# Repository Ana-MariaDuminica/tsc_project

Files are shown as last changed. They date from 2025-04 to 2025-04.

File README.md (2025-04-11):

# TSC-Project

## BOM (Bill Of Materials)

| Component | Supplier Link | Datasheet |
|---|---|---|
| 112A-TAAR-R03 | [Model](https://store.comet.srl.ro/Catalogue/Product/43497/) | [Datasheet](https://www.snapeda.com/parts/112A-TAAR-R03/Attend/datashee)|
| 744043680 | [Model](https://ro.mouser.com/ProductDetail/Wurth-Elektronik/744043680?qs=PGXP4M47uW6VkZq%252BkzjrHA%3D%3D) | [Datasheet](https://www.we-online.com/components/products/datasheet/744043680.pdf) |
| BD5229G-TR | [Model](https://componentsearchengine.com/part-view/BD5229G-TR/ROHM%20Semiconductor) | [Datasheet](https://fscdn.rohm.com/en/products/databook/datasheet/ic/power/voltage_detector/bd52xxg-e.pdf) |
| Capacitor 0402  | [Model](https://ro.mouser.com/c/passive-components/capacitors/ceramic-capacitors/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) | [Datasheet](https://componentsearchengine.com/Datasheets/2/CC0402MRX5R5BB106.pdf) |
| CPH3225A | [Model](https://www.snapeda.com/parts/CPH3225A/Seiko+Instruments/view-part/?ref=snap) | [Datasheet](https://www.snapeda.com/parts/CPH3225A/Seiko%20Instruments/datasheet/) |
| Custom Button | [Model](https://industry.panasonic.com/global/en/products/control/switch/light-touch/number/evqpuj02k) | [Datasheet](https://industry.panasonic.com/global/en/downloads?tab=catalog&small_g_cd=203&part_no=EVQPUJ02K) |
| DS3231SN | [Model](https://www.snapeda.com/parts/DS3231SN%23/Analog+Devices/view-part/?ref=eda) | [Datasheet](https://www.snapeda.com/parts/DS3231SN%23/Analog%20Devices/datasheet/) |
| ESP32 WROVER 0805 Capacitor | [Model](https://github.com/anaobreja/TSC-Project/blob/main) | [Datasheet](https://github.com/anaobreja/TSC-Project/blob/main) |
| ESP32 WROVER BME680 Sensor | [Model](https://www.snapeda.com/parts/BME680/Bosch/view-part/?welcome=home) | [Datasheet](https://www.bosch-sensortec.com/media/boschsensortec/downloads/datasheets/bst-bme680-ds001.pdf) |
| ESP32 WROVER MCP73831 Power Management | [Model](https://www.snapeda.com/parts/BME680/Bosch/view-part/?welcome=home) | [Datasheet](https://www.snapeda.com/parts/MCP73831T-2ACI/OT/Microchip/datasheet/) |
| ESP32C6 Varistor 1812 | [Model](https://github.com/anaobreja/TSC-Project/blob/main) | [Datasheet](https://github.com/anaobreja/TSC-Project/blob/main) |
| ESP32C6 WROOM-1-N8 | [Model](https://www.snapeda.com/parts/ESP32-C6-WROOM-1-N8/Espressif+Systems/view-part/?ref=eda) | [Datasheet](https://www.snapeda.com/parts/ESP32-C6-WROOM-1-N8/Espressif%20Systems/datasheet/) |
| FH34SRJ-24S-0.5SH | [Model](https://ro.mouser.com/ProductDetail/Hirose-Connector/FH34SRJ-24S-0.5SH99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) | [Datasheet](https://www.snapeda.com/parts/FH34SRJ-24S-0.5SH(99)/Hirose%20Connector/datasheet/) |
| LED Chip 0603 | [Model](https://www.snapeda.com/parts/KP-1608SURCK/Kingbright/view-part/?ref=search&t=LED%200603) | [Datasheet](https://www.snapeda.com/parts/KP-1608SURCK/Kingbright/datasheet/) |
| MAX17048G+T10 | [Model](https://www.snapeda.com/parts/MAX17048G+T10/Analog+Devices/view-part/?ref=eda) | [Datasheet](https://www.snapeda.com/parts/MAX17048G+T10/Analog%20Devices/datasheet/) |
| MBR0530 Schottky Diode | [Model](https://www.snapeda.com/parts/MBR0530/Onsemi/view-part/?ref=snap) | [Datasheet](https://www.snapeda.com/parts/MBR0530/ON%20Semiconductor/datasheet/) |
| PGB1010603MR | [Model](https://www.snapeda.com/parts/PGB1010603MR/Littelfuse/view-part/?ref=eda) | [Datasheet](https://www.snapeda.com/parts/PGB1010603MR/Littelfuse%20Inc./datasheet/) |
| QWIIC Connector | [Model](https://www.snapeda.com/parts/PRT-14417/SparkFun/view-part/) | [Datasheet](https://www.snapeda.com/parts/PRT-14417/SparkFun%20Electronics/datasheet/) |
| RCL CPOL 3528 | [Model](https://www.snapeda.com/parts/CPH3225A/Seiko+Instruments/view-part/?ref=eda) | [Datasheet](https://s3.amazonaws.com/snapeda/datasheet/TAJB475K025RNJ_AVX.pdf) |
| Resistor 0402 | [Model](https://grabcad.com/library/resistor-0402-1) | [Datasheet](https://www.yageo.com/upload/media/product/products/datasheet/rchip/PYu-RC_Group_51_RoHS_L_12.pdf) |
| SI1308EDL-T1-GE3 MOSFET | [Model](https://www.snapeda.com/parts/SI1308EDL-T1-GE3/Vishay+Siliconix/view-part/?welcome=home&ref=eda) | [Datasheet](https://www.snapeda.com/parts/SI1308EDL-T1-GE3/Vishay%20Siliconix/datasheet/) |
| SJ | [Model](https://grabcad.com/library/solder-jumpers-1) | [Datasheet](https://github.com/anaobreja/TSC-Project/blob/main) |
| USB4110-GF-A | [Model](https://componentsearchengine.com/part-view/USB4110-GF-A/GCT%20(GLOBAL%20CONNECTOR%20TECHNOLOGY)) | [Datasheet](https://gct.co/files/drawings/usb4110.pdf) |
| USBLC6-2SC6Y | [Model](https://www.snapeda.com/parts/USBLC6-2SC6Y/STMicroelectronics/view-part/?welcome=home&ref=eda) | [Datasheet](https://www.winbond.com/resource-files/W25Q512JV%20SPI%20RevB%2006252019%20KMS.pdf) |
| W25Q512JVEIQ | [Model](https://www.snapeda.com/parts/W25Q512JVEIQ/Winbond+Electronics/view-part/?ref=eda) | [Datasheet](https://www.winbond.com/resource-files/W25Q512JV%20SPI%20RevB%2006252019%20KMS.pdf) |
| XC6220A331MR-G | [Model](https://componentsearchengine.com/part-view/XC6220A331MR-G/Torex) | [Datasheet](https://product.torexsemi.com/system/files/series/xc6220.pdf) |

## Hardware Description

**Microcontroller – ESP32-C6-WROOM-1-N8**  
The ESP32-C6 serves as the central processing unit, responsible for handling all system-level operations, communication with peripherals, and power management.  
**Architecture:** RISC-V 32-bit, **Clock Speed:** 160 MHz, **Wireless Connectivity:** 2.4 GHz Wi-Fi 6, Bluetooth 5.0  

**Power Management & Battery**  
Battery Type: Li-Po (Lithium Polymer), Capacity: 3.7V 1800mAh, Charging Circuit: MCP73831T, Input Voltage: 5V via USB-C, Protection Features: Overcharge and deep discharge protection, Voltage Regulator: LDO regulator providing 3.3V stable output  

**Display – E-Paper (E-Ink)**  
Screen Size: 7.5 inches, Resolution: 800x480 pixels, Communication Interface: SPI  

**SD Card Module**  
Type: MicroSD (supports FAT32), Interface: SPI  

**External NOR Flash**  
Capacity: 64MB, Interface: SPI  

**Environmental Sensor – BME688**  
Functions: Measures temperature, humidity, pressure, and gas levels, Communication Interface: I2C  

**Real-Time Clock (RTC) – DS3231SN**  
Functionality: Maintains time and date during power-off, Communication Interface: I2C  

**USB-C Connector & ESD Protection**  
Functionality: Provides power and data transfer, Protection: ESD protection and Schottky diode for reverse polarity  

**Buttons & User Input**  
Tactile push buttons for user interaction  

**Communication Interfaces**  
GPIO: Button control and general I/O, SPI: SD Card, NOR Flash, E-Paper Display, I2C: BME688 and DS3231SN, UART: Serial communication and debugging, Wi-Fi & Bluetooth: via ESP32-C6  

## Power Consumption Estimation
| Component | Current Draw (mA) | Voltage (V) | Power (mW) | Typical Current Range (mA) | Notes |
|---|---|---|---|---|---|
| ESP32-C6 (Wi-Fi active) | 140 | 3.3 | 462 | 120 – 160 | High usage during communication |
| E-Paper Display (Updating) | 20 | 3.3 | 66 | 15 – 26 | Active only during refresh |
| BME688 Sensor (Measuring) | 2.1 | 3.3 | 6.93 | 1.7 – 3.1 | Low-power environmental sensing |
| RTC Module (Active) | 0.8 | 3.3 | 2.64 | 0.5 – 1 | Minimal power requirement |
| SD Card (Active) | 60 | 3.3 | 198 | 30 – 100 | Used during data access |
| External NOR Flash (e.g. W25Q32) | 10 | 3.3 | 33 | 4 – 20 | Accessed for storage operations |

## ESP32-C6 Pin Mapping

| Component | Interface | Purpose | ESP32-C6 Pin(s) |
|---|---|---|---|
| E-Paper Display | SPI | Transfers image data to the display and controls its state | IO7 (MOSI), IO6 (SCK), IO10 (CS), IO5 (DC), IO23 (RST), IO3 (BUSY) |
| MicroSD Card | SPI | Allows storage and retrieval of e-book files | IO7 (MOSI), IO6 (SCK), IO4 (SS_SD), IO2 (MISO) |
| Environmental Sensor (BME688) | I2C | Reads temperature, humidity, pressure, and air quality data | IO21 (SDA), IO22 (SCL) |
| USB-C Connection | USB | Powers and programs the ESP32-C6 | GPIOs through voltage regulation |
| Control Buttons | GPIO | User input for device interactions | IO9 (BOOT), IO15 (CHANGE), EN (RESET) |
| RTC Module (DS3231) | I2C | Keeps track of time even when ESP32 is off | IO21 (SDA), IO22 (SCL), IO18 (RST), IO1 (32KHz), IO0 (INT_RTC) |
| External NOR Flash | SPI | Provides additional storage for application data | IO11 (CS), IO6 (SCK), IO2 (MISO), IO7 (MOSI) |
| Battery Monitoring | I2C | Reads battery voltage and charge status | IO21 (SDA), IO22 (SCL) |

## Design Notes

- The final PCB layout includes approximately **120 vias**, used primarily to optimize routing between layers while keeping signal integrity and clearance constraints in check.

- The following footprint and pad adjustments were manually made for compatibility with routing rules (specifically Copper Width DRC):

  **1. Inductor – L1 (IND_4828-WE-TPC_WRE)**  
  Footprint pad size was increased to **32mil × 16mil** to accommodate 0.3 mm (11.8mil) power traces without triggering DRC width violations.

  **2. Fuel Gauge – U4 (MAX17048G+T10, footprint SON50P200X200X80-9N)**  
  The original pad size of **29.92mil × 10.63mil** was modified to **32mil × 16mil** to ensure proper trace connection without violating clearance or minimum width rules.

- These changes ensure that all traces, especially for power delivery, comply with the netclass requirements (e.g., minimum 0.3 mm width for VBAT, VBUS, etc.) and eliminate false-positive DRC errors.

## Block Diagram

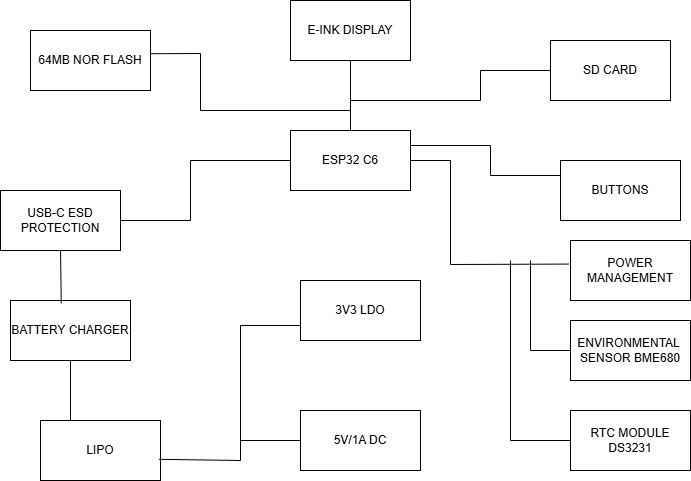
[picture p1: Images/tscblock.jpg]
Block Diagram


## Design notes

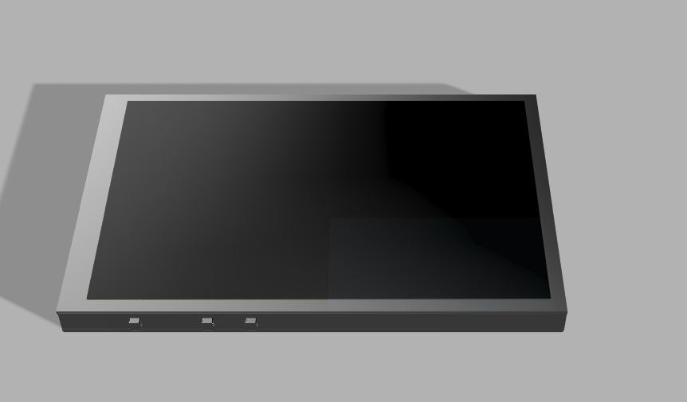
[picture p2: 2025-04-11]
Images/3d_model_image.png

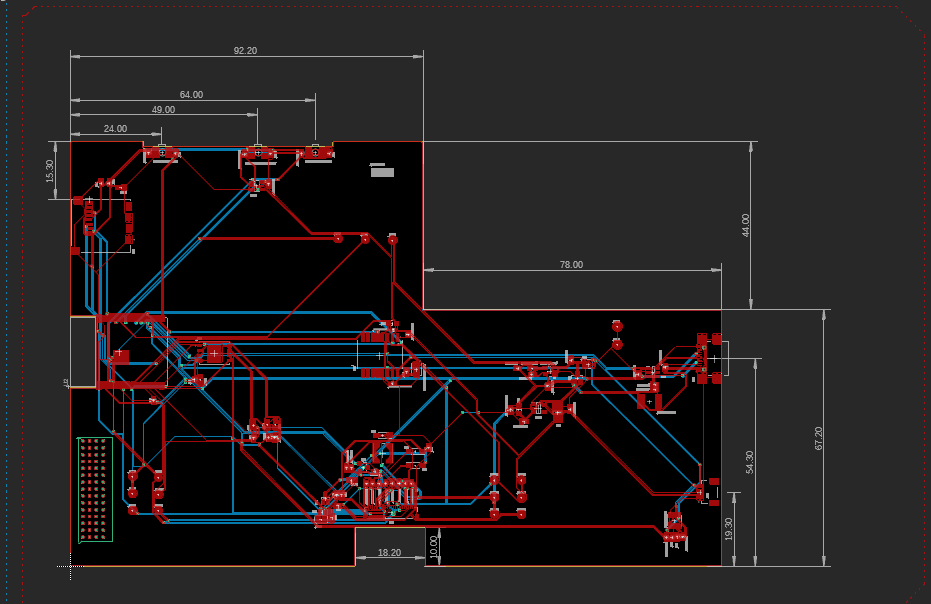
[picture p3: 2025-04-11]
Images/pcb2.png

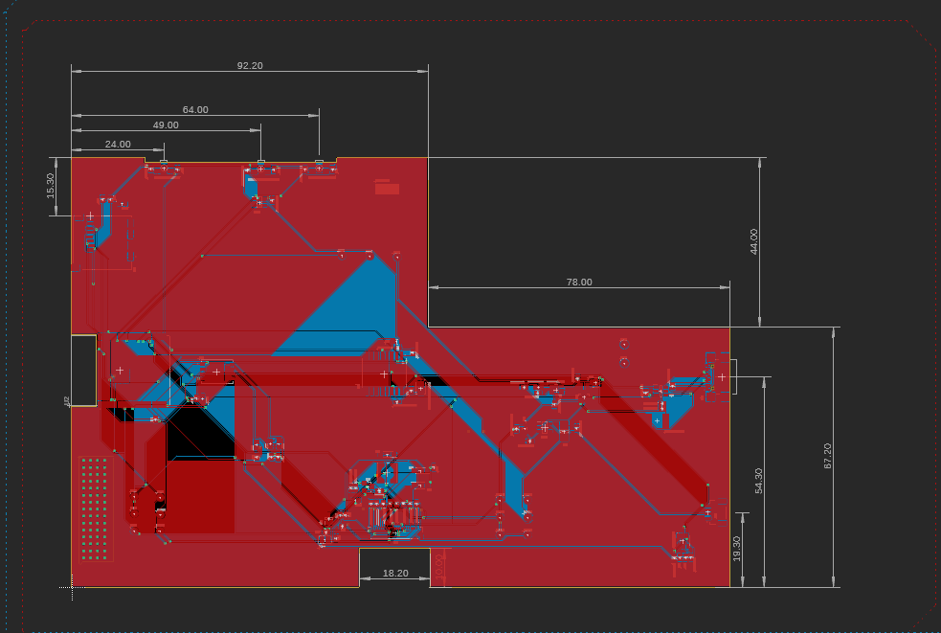
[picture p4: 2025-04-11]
Images/pcb1.png

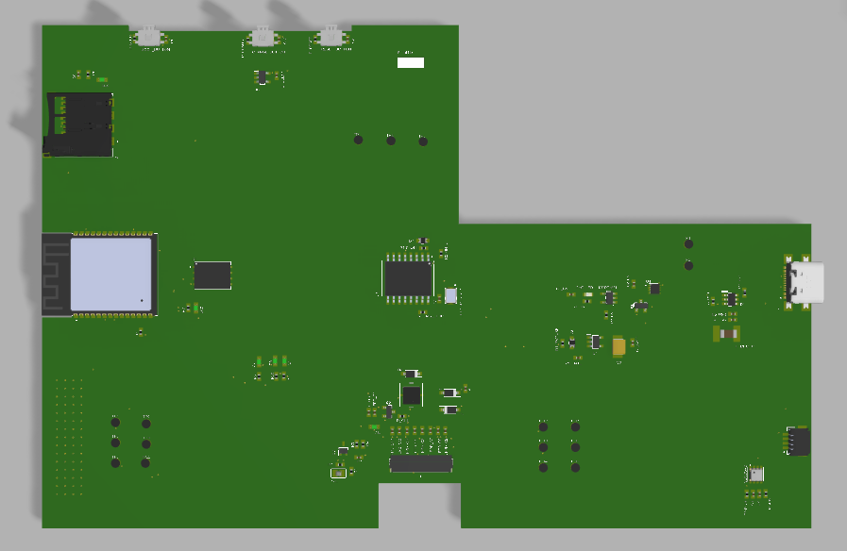
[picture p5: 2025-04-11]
Images/3d_board.png

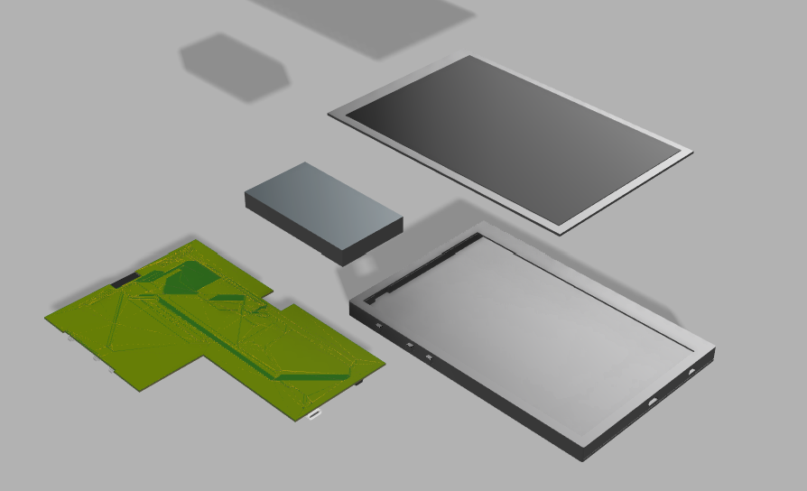
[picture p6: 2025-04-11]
Images/exploded_image.png

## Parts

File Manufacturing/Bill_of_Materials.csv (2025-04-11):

Qty | Value | Device | Package | Parts | Description | ARROW_PART_NUMBER | ARROW_PRICE-STOCK | AVAILABILITY | CENTROID_NOT_SPECIFIED | CHECK_PRICES | COPYRIGHT | DATASHEET | DESCRIPTION | DIGIKEY_DESCRIPTION | DIGIKEY_PART_NUMBER | HEIGHT | LEAD_FREE | MANUFACTURER_NAME | MANUFACTURER_PART_NUMBER | MF | MFR_NAME | MOUSER_PART_NUMBER | MOUSER_PRICE-STOCK | MOUSER_TESTING_PART_NUMBER | MOUSER_TESTING_PRICE-STOCK | MP | MPN | PACKAGE | POPULARITY | PREFIX | PRICE | PROD_ID | PURCHASE-URL | ROHS | SNAPEDA_LINK | SPICEMODEL | SPICEPREFIX | TEMPERATURE_RANGE_HIGH | TEMPERATURE_RANGE_LOW | TP_SIGNAL_NAME | VALUE
1 |  | ADAFRUIT_LEDCHIP-LED0603 | ADAFRUIT_CHIP-LED0603 | CHG_LED | LED
1 |  | SJ | SJ | SJ1 | SMD solder JUMPER |  |  |  |  |  |  |  |  |  |  |  |  |  |  |  |  |  |  |  |  |  |  |  | 3
1 | 0.1uF/50V | ESP32_WROVER_EAGLE-LTSPICE_CC0402 | ESP32_WROVER_EAGLE-LTSPICE_C0402 | EPD_C5 | CAPACITOR, European symbol |  |  |  |  |  |  |  |  |  |  |  |  |  |  |  |  |  |  |  |  |  |  |  |  |  |  |  |  |  |  | NONE | C
1 | 0.47 | ESP32_WROVER_EAGLE-LTSPICE_RR0402 | ESP32_WROVER_EAGLE-LTSPICE_R0402 | R3 | RESISTOR, European symbol |  |  |  |  |  |  |  |  |  |  |  |  |  |  |  |  |  |  |  |  |  |  |  |  |  |  |  |  |  |  | NONE | R
1 | 100K | ESP32_WROVER_EAGLE-LTSPICE_RR0402 | ESP32_WROVER_EAGLE-LTSPICE_R0402 | R1_PWRUSB | RESISTOR, European symbol |  |  |  |  |  |  |  |  |  |  |  |  |  |  |  |  |  |  |  |  |  |  |  |  |  |  |  |  |  |  | NONE | R
3 | 100nF | EAGLE-LTSPICE_CC0402 | EAGLE-LTSPICE_C0402 | C4_USB, C8, C9 | CAPACITOR, European symbol |  |  |  |  |  |  |  |  |  |  |  |  |  |  |  |  |  |  |  |  |  |  |  |  |  |  |  |  |  |  | NONE | C
5 | 100nF | ESP32_WROVER_EAGLE-LTSPICE_CC0402 | ESP32_WROVER_EAGLE-LTSPICE_C0402 | C1, C2, C6, C10, C_DELAY | CAPACITOR, European symbol |  |  |  |  |  |  |  |  |  |  |  |  |  |  |  |  |  |  |  |  |  |  |  |  |  |  |  |  |  |  | NONE | C
1 | 100uF TANT | RCL_CPOL-EUCT3528 | RCL_CT3528 | C3 | POLARIZED CAPACITOR, European symbol |  |  |  |  |  |  |  |  |  |  |  |  |  |  |  |  |  |  |  |  |  |  |  | 0 |  |  |  |  |  |  |  | C
16 | 10K | ESP32_WROVER_EAGLE-LTSPICE_RR0402 | ESP32_WROVER_EAGLE-LTSPICE_R0402 | R1, R1-PINH, R1-PINH1, R2-PINH, R2-PINH1, R4, R5, R6, R7, R8, R9, R10, R_BOOT, R_CHANGE, R_CL1, R_RESET | RESISTOR, European symbol |  |  |  |  |  |  |  |  |  |  |  |  |  |  |  |  |  |  |  |  |  |  |  |  |  |  |  |  |  |  | NONE | R
1 | 10uF | EAGLE-LTSPICE_CC0402 | EAGLE-LTSPICE_C0402 | C7 | CAPACITOR, European symbol |  |  |  |  |  |  |  |  |  |  |  |  |  |  |  |  |  |  |  |  |  |  |  |  |  |  |  |  |  |  | NONE | C
1 | 112A-TAAR-R03_ATTEND | 112A-TAAR-R03_ATTEND | 112ATAARR03ATTEND | J4 | Micro SD Card Socket, Push-Push Type, Top Mount, SMT, H=1.83mm, 10u |  |  |  |  |  |  |  | Micro SD Card Socket | Push-Push Type | Top Mount | SMT | H=1.83mm | 10u |  |  | 1.9mm |  | ATTEND | 112A-TAAR-R03 ATTEND
1 | 15 | ESP32_WROVER_EAGLE-LTSPICE_RR0402 | ESP32_WROVER_EAGLE-LTSPICE_R0402 | R_CAPACITOR | RESISTOR, European symbol |  |  |  |  |  |  |  |  |  |  |  |  |  |  |  |  |  |  |  |  |  |  |  |  |  |  |  |  |  |  | NONE | R
1 | 1uF | ESP32_WROVER_EAGLE-LTSPICE_CC0402 | ESP32_WROVER_EAGLE-LTSPICE_C0402 | C5 | CAPACITOR, European symbol |  |  |  |  |  |  |  |  |  |  |  |  |  |  |  |  |  |  |  |  |  |  |  |  |  |  |  |  |  |  | NONE | C
9 | 1uF/50V | ESP32_WROVER_EAGLE-LTSPICE_CC0402 | ESP32_WROVER_EAGLE-LTSPICE_C0402 | EPD_C1, EPD_C2, EPD_C6, EPD_C7, EPD_C8, EPD_C9, EPD_C10, EPD_C11, EPD_C12 | CAPACITOR, European symbol |  |  |  |  |  |  |  |  |  |  |  |  |  |  |  |  |  |  |  |  |  |  |  |  |  |  |  |  |  |  | NONE | C
1 | 2.2 | ESP32_WROVER_EAGLE-LTSPICE_RR0402 | ESP32_WROVER_EAGLE-LTSPICE_R0402 | R2 | RESISTOR, European symbol |  |  |  |  |  |  |  |  |  |  |  |  |  |  |  |  |  |  |  |  |  |  |  |  |  |  |  |  |  |  | NONE | R
1 | 200 | ESP32_WROVER_EAGLE-LTSPICE_RR0402 | ESP32_WROVER_EAGLE-LTSPICE_R0402 | R1_BAT | RESISTOR, European symbol |  |  |  |  |  |  |  |  |  |  |  |  |  |  |  |  |  |  |  |  |  |  |  |  |  |  |  |  |  |  | NONE | R
2 | 20V/4.2A/52m?/1.4W | ESP32_WROVER_SPARKFUN-DISCRETESEMI_MOSFET_PCH-DMG2305UX-7 | ESP32_WROVER_SPARKFUN-DISCRETESEMI_SOT23-3 | Q1, Q2 | P-channel MOSFETs |  |  |  |  |  |  |  |  |  |  |  |  |  |  |  |  |  |  |  |  |  |  |  |  |  |  | TRAN-14388 |  |  |  |  |  |  |  |  | 20V/4.2A/52m?/1.4W
1 | 2K | ESP32_WROVER_EAGLE-LTSPICE_RR0402 | ESP32_WROVER_EAGLE-LTSPICE_R0402 | R2_BAT | RESISTOR, European symbol |  |  |  |  |  |  |  |  |  |  |  |  |  |  |  |  |  |  |  |  |  |  |  |  |  |  |  |  |  |  | NONE | R
3 | 4.7uF | EAGLE-LTSPICE_CC0402 | EAGLE-LTSPICE_C0402 | C1_BAT1, C1_BAT2, C5_USB | CAPACITOR, European symbol |  |  |  |  |  |  |  |  |  |  |  |  |  |  |  |  |  |  |  |  |  |  |  |  |  |  |  |  |  |  | NONE | C
2 | 4.7uF | ESP32_WROVER_EAGLE-LTSPICE_CC0402 | ESP32_WROVER_EAGLE-LTSPICE_C0402 | C1_BAT, C2_BAT | CAPACITOR, European symbol |  |  |  |  |  |  |  |  |  |  |  |  |  |  |  |  |  |  |  |  |  |  |  |  |  |  |  |  |  |  | NONE | C
1 | 4.7uF/25V | EAGLE-LTSPICE_CC0402 | EAGLE-LTSPICE_C0402 | C4 | CAPACITOR, European symbol |  |  |  |  |  |  |  |  |  |  |  |  |  |  |  |  |  |  |  |  |  |  |  |  |  |  |  |  |  |  | NONE | C
2 | 5k1 | ESP32_WROVER_EAGLE-LTSPICE_RR0402 | ESP32_WROVER_EAGLE-LTSPICE_R0402 | R2-USB, R2-USB1 | RESISTOR, European symbol |  |  |  |  |  |  |  |  |  |  |  |  |  |  |  |  |  |  |  |  |  |  |  |  |  |  |  |  |  |  | NONE | R
1 | 68uH | 744043680IND_4828-WE-TPC_WRE | IND_4828-WE-TPC_WRE | L1 |  |  |  |  |  |  | Copyright (C) 2024 Ultra Librarian. All rights reserved. |  |  |  |  |  |  |  | 744043680 |  | Wurth Electronics
1 | BD5229G-TR | BD5229G-TR | SOT95P280X125-5N | IC1 | Voltage Detector with Adjustable Delay Time: CMOS processes are utilized to develop high precision, low current consumption CMOS reset ICs that allow arbitrary setting of the delay time. The extensive lineup includes both Nch Open Drain and CMOS output types in a wide range of detection voltages (from 2.3V to 6.0V, in 0.1V steps), enabling selection of the ideal solution based on customer requirements. In addition, the entire series is of course both lead-free and RoHS-compliant. |  |  |  |  |  |  |  | Voltage Detector with Adjustable Delay Time: CMOS processes are utilized to develop high precision | low current consumption CMOS reset ICs that allow arbitrary setting of the delay time. The extensive lineup includes both Nch Open Drain and CMOS output types in a wide range of detection voltages (from 2.3V to 6.0V | in 0.1V steps) | enabling selection of the ideal solution based on customer requirements. In addition | the entire series is of course both lead-free and RoHS-compliant. |  |  | 1.25mm |  | ROHM Semiconductor | BD5229G-TR |  |  | 755-BD5229G-TR | https://www.mouser.co.uk/ProductDetail/ROHM-Semiconductor/BD5229G-TR?qs=4kLU8WoGk0vvnhrrYwdszw%3D%3D
1 | BME688 | ESP32_WROVER_BME680_BME680 | ESP32_WROVER_BME680_PSON80P300X300X100-8N | SENSOR2 | Integrated Environmental Unit |  |  | Unavailable |  |  |  |  | Integrated Environmental Unit |  |  |  |  |  |  | Bosch Sensortec |  |  |  |  |  | BME680 |  | LGA-8 Bosch Tools |  |  | None
3 | BUTTON_CUSYOMV1 | BUTTON_CUSYOMV1 | MYBUTTON | BOOT_BUTTON, CHANGE_BUTTON, RESET_BUTTON
1 | CPH3225A | CPH3225A | CAPCP3225X100N | C10_SUPERCAP | Cap 0.011F 3.3V 1210 Flat Check availability |  |  | Not in stock |  | https://www.snapeda.com/parts/CPH3225A/Seiko+Instruments/view-part/?ref=eda |  |  | 11 mF (EDLC) Supercapacitor 3.3 V 1210 (3225 Metric) - - |  |  |  |  |  |  | Seiko Instruments |  |  |  |  |  | CPH3225A |  | 1210 Seiko |  |  | None |  | https://www.snapeda.com/api/url_track_click_mouser/?unipart_id=562593&manufacturer=Seiko Instruments&part_name=CPH3225A&search_term=None |  | https://www.snapeda.com/parts/CPH3225A/Seiko+Instruments/view-part/?ref=snap
1 | DS3231SN# | DS3231SN# | SOIC127P1032X265-16N | U3 | Real Time Clock Serial 16-Pin SOIC W T/R Check availability |  |  | In Stock |  | https://www.snapeda.com/parts/DS3231SN%23/Analog+Devices/view-part/?ref=eda |  |  | Extremely Accurate I2C-Integrated RTC/TCXO/Crystal |  |  |  |  |  |  | Analog Devices |  |  |  |  |  | DS3231SN# |  | SOIC-16 Maxim |  |  | None |  | https://www.snapeda.com/api/url_track_click_mouser/?unipart_id=99048&manufacturer=Analog Devices&part_name=DS3231SN#&search_term=None |  | https://www.snapeda.com/parts/DS3231SN%23/Analog+Devices/view-part/?ref=snap
1 | ESP32-C6-WROOM-1-N8 | ESP32-C6-WROOM-1-N8 | XCVR_ESP32-C6-WROOM-1-N8 | U2 | Check availability |  |  | In Stock |  | https://www.snapeda.com/parts/ESP32-C6-WROOM-1-N8/Espressif+Systems/view-part/?ref=eda |  |  | Multiprotocol Modules ESP32-C6 module | Wi-Fi 6 in 2.4 GHz band | Bluetooth 5 | Zigbee 3.0 and Thread. ESP34-WROOM Compatible - ENGINEERING SAMPLE |  |  |  |  |  |  | Espressif Systems |  |  |  |  |  | ESP32-C6-WROOM-1-N8 |  | None |  |  | None |  |  |  | https://www.snapeda.com/parts/ESP32-C6-WROOM-1-N8/Espressif+Systems/view-part/?ref=snap
1 | ESP32C6_VARISTORCN1812 | ESP32C6_VARISTORCN1812 | ESP32C6_VARISTOR_CT/CN1812 | PFMF.050.1 | VARISTOR |  |  |  |  |  |  |  |  |  |  |  |  |  |  |  |  |  |  |  |  |  |  |  | 0
1 | ESP32_WROVER_SPARKFUN-IC-POWER_MCP73831 | ESP32_WROVER_SPARKFUN-IC-POWER_MCP73831 | ESP32_WROVER_SPARKFUN-IC-POWER_SOT23-5 | MCP73831 | MCP73831T Li-Ion, Li-Pol Controller |  |  |  |  |  |  |  |  |  |  |  |  |  |  |  |  |  |  |  |  |  |  |  |  |  |  | IC-09995
1 | FH34SRJ-24S-0.5SH_99_ | FH34SRJ-24S-0.5SH_99_ | FH34SRJ24S05SH99 | J1 | (0.50mm) Surface Mount, Right Angle |  |  |  |  |  |  |  | 24 Position FFC | FPC Connector Contacts | (0.50mm) Surface Mount | Right Angle |  |  | 1.1mm |  | Hirose | FH34SRJ-24S-0.5SH(99) |  |  | 798-FH34SRJ24S05SH99 | https://www.mouser.co.uk/ProductDetail/Hirose-Connector/FH34SRJ-24S-0.5SH99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
1 | MAX17048G+T10 | MAX17048G+T10 | SON50P200X200X80-9N | U4 | Check availability |  |  | In Stock |  | https://www.snapeda.com/parts/MAX17048G+T10/Analog+Devices/view-part/?ref=eda |  |  | 3µA 1-Cell/2-Cell Fuel Gauge with ModelGauge |  |  |  |  |  |  | Analog Devices |  |  |  |  |  | MAX17048G+T10 |  | TDFN-8 Maxim |  |  | None |  | https://www.snapeda.com/api/url_track_click_mouser/?unipart_id=329239&manufacturer=Analog Devices&part_name=MAX17048G+T10&search_term=None |  | https://www.snapeda.com/parts/MAX17048G+T10/Analog+Devices/view-part/?ref=snap
3 | MBR0530 | MBR0530 | SOD3716X135N | D3, D4, D5 | ON SEMICONDUCTOR - MBR0530 - DIODE, SCHOTTKY, 0.5A, 30V, SOD-123 |  |  | In Stock |  | https://www.snapeda.com/parts/MBR0530/Onsemi/view-part/?ref=eda |  |  | Diode Schottky 30 V 500mA Surface Mount SOD-123 |  |  |  |  |  |  | ON Semiconductor |  |  |  |  |  | MBR0530 |  | SOD-123-2 ON Semiconductor |  |  | None |  | https://www.snapeda.com/api/url_track_click_mouser/?unipart_id=179458&manufacturer=ON Semiconductor&part_name=MBR0530&search_term=None |  | https://www.snapeda.com/parts/MBR0530/Onsemi/view-part/?ref=snap
6 | PGB1010603MR | PGB1010603MR | DIOC1608X36N | D6, D8, D9, D10, D11, D12 | Check availability |  |  | In Stock |  | https://www.snapeda.com/parts/PGB1010603MR/Littelfuse/view-part/?ref=eda |  |  | 150V (Typ) Clamp - Ipp Tvs Diode Surface Mount 0603 (1608 Metric) |  |  |  |  |  |  | Littelfuse Inc. |  |  |  |  |  | PGB1010603MR |  | 0603 Littelfuse Inc. |  |  | None |  | https://www.snapeda.com/api/url_track_click_mouser/?unipart_id=5659453&manufacturer=Littelfuse Inc.&part_name=PGB1010603MR&search_term=None |  | https://www.snapeda.com/parts/PGB1010603MR/Littelfuse/view-part/?ref=snap
1 | QWIIC_RIGHT_ANGLE | QWIIC_CONNECTORJS-1MM | JST04_1MM_RA | J3 | SparkFun I2C Standard Qwiic Connector |  |  |  |  |  |  |  |  |  |  |  |  |  |  |  |  |  |  |  |  |  |  |  |  |  |  | CONN-13694 |  |  |  |  |  |  |  |  | QWIIC_RIGHT_ANGLE
1 | SAMACSYS_PARTS_USB4110-GF-A | SAMACSYS_PARTS_USB4110-GF-A | SAMACSYS_PARTS_USB4110GFA | J2 | CONN USB 2.0 TYPE-C R/A SMT |  |  |  |  |  |  |  | CONN USB 2.0 TYPE-C R/A SMT |  |  | 3.26mm |  | GCT (GLOBAL CONNECTOR TECHNOLOGY) | USB4110-GF-A |  |  | 640-USB4110-GF-A | https://www.mouser.co.uk/ProductDetail/GCT/USB4110-GF-A?qs=KUoIvG%2F9IlYiZvIXQjyJeA%3D%3D
2 | SD0805S020S1R0 | ESP32_WROVER_AVX---SD0805S020S1R0_AVX_SD0805S020S1R0_0_0AVX_SD0805S020S1R0_0_0 | ESP32_WROVER_AVX---SD0805S020S1R0_AVX_SD0805S020S1R0_0 | D2, D7 | Schottky Barrier Rectifier Diode |  |  |  | No |  |  | http://datasheets.avx.com/schottky.pdf |  | DIODE SCHOTTKY 20V 1A 0805 | 478-7800-1-ND |  | yes |  |  | AVX |  | 581-SD0805S020S1R0 |  |  |  |  |  | 0805 (2012 metric) |  | D |  |  |  | yes |  |  |  | +125°C | -55°C
1 | SI1308EDL-T1-GE3 | SI1308EDL-T1-GE3 | SOT65P210X110-3N | Q3 | MOSFET N-Ch 30V 1.5A TrenchFET SC70 Vishay Si1308EDL-T1-GE3 N-channel MOSFET Transistor, 1.5 A, 30 V, 3-Pin SC-70 |  |  | In Stock |  | https://www.snapeda.com/parts/SI1308EDL-T1-GE3/Vishay+Siliconix/view-part/?ref=eda |  |  | Si1308EDL-T1-GE3 N-channel MOSFET Transistor | 1.5 A | 30 V | 3-Pin SC-70 | Siliconix / Vishay SI1308EDL-T1-GE3 |  |  |  |  |  |  | Vishay Siliconix |  |  |  |  |  | SI1308EDL-T1-GE3 |  | SOT-323 Vishay Semiconductor |  |  | None |  | https://www.snapeda.com/api/url_track_click_mouser/?unipart_id=274603&manufacturer=Vishay Siliconix&part_name=SI1308EDL-T1-GE3&search_term=None |  | https://www.snapeda.com/parts/SI1308EDL-T1-GE3/Vishay+Siliconix/view-part/?ref=snap
17 | TPTP20R | TPTP20R | TP20R | TP1, TP2, TP3, TP4, TP5, TP6, TP7, TP8, TP9, TP10, TP11, TP12, TP13, TP14, TP15, TP16, TP17 | Test pad |  |  |  |  |  |  |  |  |  |  |  |  |  |  |  |  |  |  |  |  |  |  |  | 2
1 | USBLC6-2SC6Y | USBLC6-2SC6Y | SOT95P280X145-6N | D1 | Low Cap. ESD Protection Auto SOT-23-6 STMicroelectronics USBLC6-2SC6Y, Dual Uni-Directional TVS Diode Array, 6-Pin SOT-23 |  |  | In Stock |  | https://www.snapeda.com/parts/USBLC6-2SC6Y/STMicroelectronics/view-part/?ref=eda |  |  | 17V Clamp 5A (8/20µs) Ipp Tvs Diode Surface Mount SOT-23-6 |  |  |  |  |  |  | STMicroelectronics |  |  |  |  |  | USBLC6-2SC6Y |  | SOT-23-6 STMicroelectronics |  |  | None |  |  |  | https://www.snapeda.com/parts/USBLC6-2SC6Y/STMicroelectronics/view-part/?ref=snap
1 | W25Q512JVEIQ | W25Q512JVEIQ | SON127P600X800X80-9N | U1 | Check availability |  |  | In Stock |  | https://www.snapeda.com/parts/W25Q512JVEIQ/Winbond+Electronics/view-part/?ref=eda |  |  | FLASH - NOR Memory IC 512Mb (64M x 8) SPI - Quad I/O 133 MHz 8-WSON (8x6) |  |  |  |  |  |  | Winbond Electronics |  |  |  |  |  | W25Q512JVEIQ |  | Package |  |  | None |  |  |  | https://www.snapeda.com/parts/W25Q512JVEIQ/Winbond+Electronics/view-part/?ref=snap
1 | XC6220A331MR-G | XC6220A331MR-G | SOT95P280X120-5N | IC4 | LDO Voltage Regulators |  |  |  |  |  |  |  | LDO Voltage Regulators |  |  | 1.2mm |  | Torex | XC6220A331MR-G |  |  | 865-XC6220A331MR-G | https://www.mouser.co.uk/ProductDetail/Torex-Semiconductor/XC6220A331MR-G?qs=AsjdqWjXhJ8ZSWznL1J0gg%3D%3D

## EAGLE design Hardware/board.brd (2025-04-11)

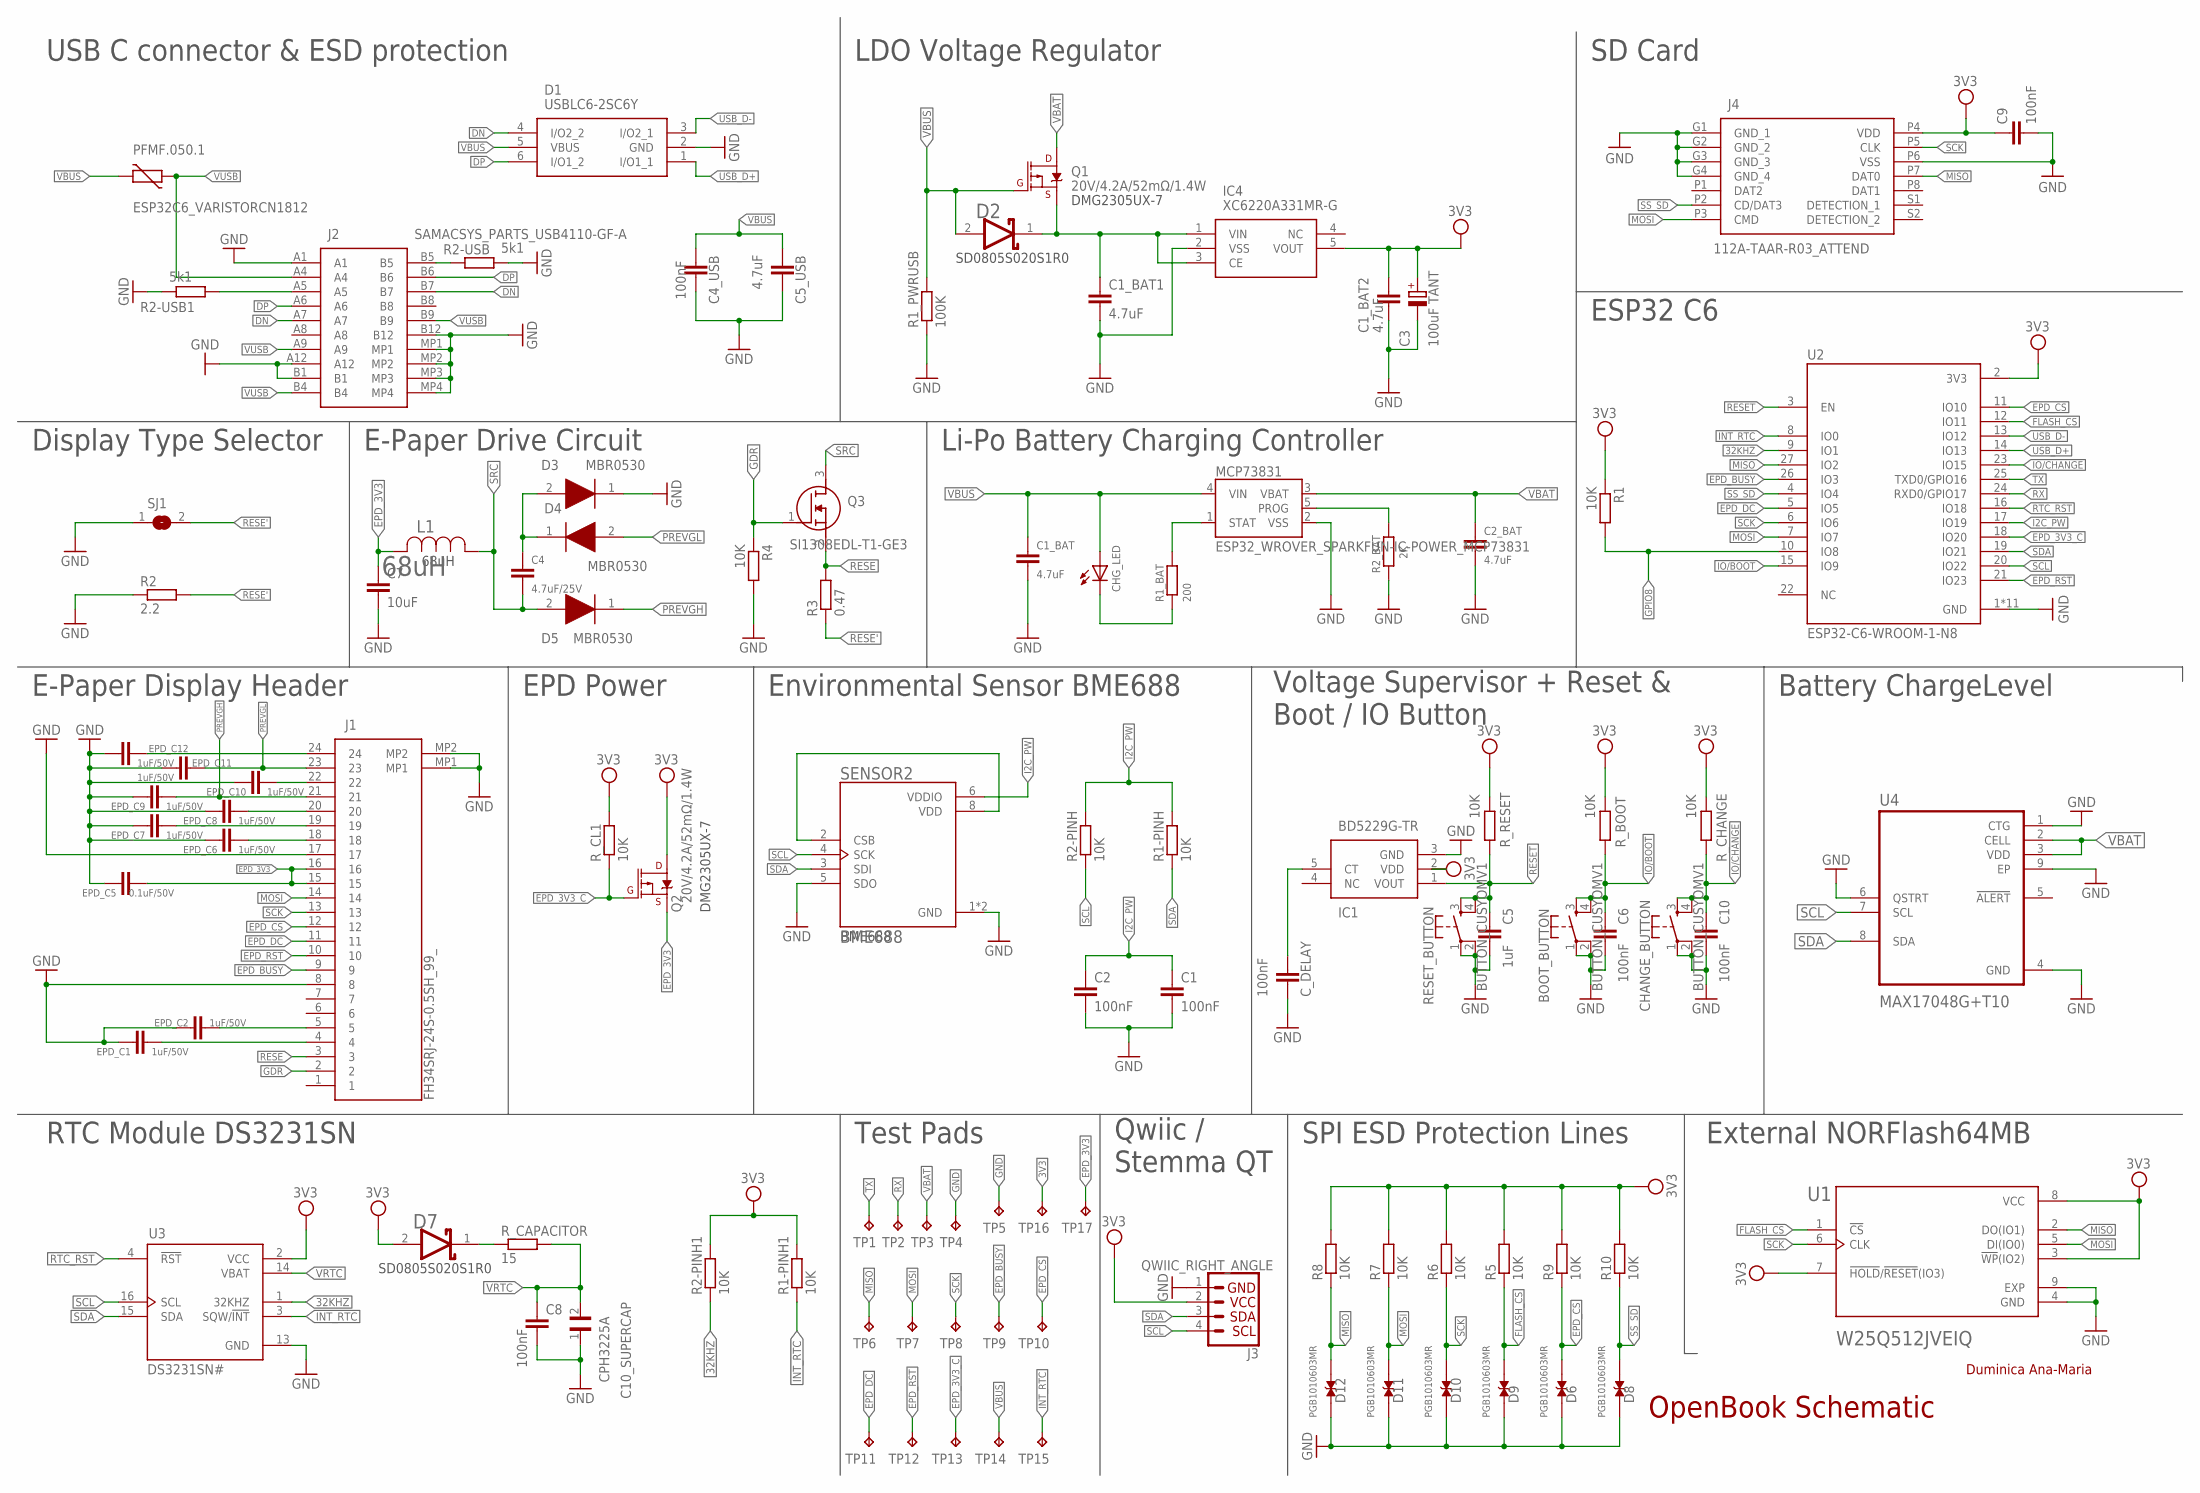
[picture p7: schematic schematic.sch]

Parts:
BOOT_BUTTON: BUTTON_CUSYOMV1; MYBUTTON
C1, C2, C6, C10: 100nF; ESP32_WROVER_EAGLE-LTSPICE_C0402
C1_BAT, C2_BAT: 4.7uF; ESP32_WROVER_EAGLE-LTSPICE_C0402
C1_BAT1, C1_BAT2, C5_USB: 4.7uF; EAGLE-LTSPICE_C0402
C3: 100uF TANT; RCL_CT3528
C4: 4.7uF/25V; EAGLE-LTSPICE_C0402
C4_USB, C8, C9: 100nF; EAGLE-LTSPICE_C0402
C5: 1uF; ESP32_WROVER_EAGLE-LTSPICE_C0402
C7: 10uF; EAGLE-LTSPICE_C0402
C10_SUPERCAP: CPH3225A; CAPCP3225X100N
CHANGE_BUTTON: BUTTON_CUSYOMV1; MYBUTTON
CHG_LED: ADAFRUIT_LEDCHIP-LED0603; ADAFRUIT_CHIP-LED0603
C_DELAY: 100nF; ESP32_WROVER_EAGLE-LTSPICE_C0402
D1: USBLC6-2SC6Y; SOT95P280X145-6N
D2, D7: SD0805S020S1R0; ESP32_WROVER_AVX---SD0805S020S1R0_AVX_SD0805S020S1R0_0
D3, D4, D5: MBR0530; SOD3716X135N
D6, D8, D9, D10, D11, D12: PGB1010603MR; DIOC1608X36N
EPD_C1, EPD_C2, EPD_C6, EPD_C7, EPD_C8, EPD_C9, EPD_C10, EPD_C11, EPD_C12: 1uF/50V; ESP32_WROVER_EAGLE-LTSPICE_C0402
EPD_C5: 0.1uF/50V; ESP32_WROVER_EAGLE-LTSPICE_C0402
IC1: BD5229G-TR; SOT95P280X125-5N
IC4: XC6220A331MR-G; SOT95P280X120-5N
J1: FH34SRJ-24S-0.5SH_99_; FH34SRJ24S05SH99
J2: SAMACSYS_PARTS_USB4110-GF-A; SAMACSYS_PARTS_USB4110GFA
J3: QWIIC_RIGHT_ANGLE; JST04_1MM_RA
J4: 112A-TAAR-R03_ATTEND; 112ATAARR03ATTEND
L1: 68uH; IND_4828-WE-TPC_WRE
MCP73831: ESP32_WROVER_SPARKFUN-IC-POWER_MCP73831; ESP32_WROVER_SPARKFUN-IC-POWER_SOT23-5
PFMF.050.1: ESP32C6_VARISTORCN1812; ESP32C6_VARISTOR_CT/CN1812
Q1, Q2: 20V/4.2A/52mΩ/1.4W; ESP32_WROVER_SPARKFUN-DISCRETESEMI_SOT23-3
Q3: SI1308EDL-T1-GE3; SOT65P210X110-3N
R1, R1-PINH, R1-PINH1, R2-PINH, R2-PINH1, R4, R5, R6, R7, R8, R9, R10: 10K; ESP32_WROVER_EAGLE-LTSPICE_R0402
R1_BAT: 200; ESP32_WROVER_EAGLE-LTSPICE_R0402
R1_PWRUSB: 100K; ESP32_WROVER_EAGLE-LTSPICE_R0402
R2: 2.2; ESP32_WROVER_EAGLE-LTSPICE_R0402
R2-USB, R2-USB1: 5k1; ESP32_WROVER_EAGLE-LTSPICE_R0402
R2_BAT: 2K; ESP32_WROVER_EAGLE-LTSPICE_R0402
R3: 0.47; ESP32_WROVER_EAGLE-LTSPICE_R0402
RESET_BUTTON: BUTTON_CUSYOMV1; MYBUTTON
R_BOOT: 10K; ESP32_WROVER_EAGLE-LTSPICE_R0402
R_CAPACITOR: 15; ESP32_WROVER_EAGLE-LTSPICE_R0402
R_CHANGE: 10K; ESP32_WROVER_EAGLE-LTSPICE_R0402
R_CL1: 10K; ESP32_WROVER_EAGLE-LTSPICE_R0402
R_RESET: 10K; ESP32_WROVER_EAGLE-LTSPICE_R0402
SENSOR2: BME688; ESP32_WROVER_BME680_PSON80P300X300X100-8N
SJ1: SJ
TP1, TP2, TP3, TP4, TP5, TP6, TP7, TP8, TP9, TP10, TP11, TP12, TP13, TP14, TP15, TP16, TP17: TPTP20R; TP20R
U1: W25Q512JVEIQ; SON127P600X800X80-9N
U2: ESP32-C6-WROOM-1-N8; XCVR_ESP32-C6-WROOM-1-N8
U3: DS3231SN#; SOIC127P1032X265-16N
U4: MAX17048G+T10; SON50P200X200X80-9N

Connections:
3V3: C1_BAT2.1, C3.+, C9.1, D7.2 (ANODE), IC1.2 (VDD), IC4.5 (VOUT), J3.2, J4.P4 (VDD), Q2.3 (D), R1.1, R1-PINH1.2, R2-PINH1.2, R5.2, R6.2, R7.2, R8.2, R9.2, R10.2, R_BOOT.2, R_CHANGE.2, R_CL1.2, R_RESET.2, TP16.TP, U1.3 (!WP!(IO2)), U1.7 (!HOLD!/!RESET!(IO3)), U1.8 (VCC), U2.2 (3V3), U3.2 (VCC)
32KHZ: R2-PINH1.1, U2.9 (IO1), U3.1 (32KHZ)
DN: D1.4 (I/O2_2), J2.A7, J2.B7
DP: D1.6 (I/O1_2), J2.A6, J2.B6
EPD_3V3: C7.1, EPD_C5.2, J1.15, J1.16, L1.2, Q2.2 (S), TP17.TP
EPD_3V3_C: Q2.1 (G), R_CL1.1, TP13.TP, U2.18 (IO20)
EPD_BUSY: J1.9, TP9.TP, U2.26 (IO3)
EPD_CS: D6.2, J1.12, R9.1, TP10.TP, U2.11 (IO10)
EPD_DC: J1.11, TP11.TP, U2.5 (IO5)
EPD_RST: J1.10, TP12.TP, U2.21 (IO23)
FLASH_CS: D9.2, R5.1, U1.1 (!CS), U2.12 (IO11)
GDR: J1.2, Q3.1 (G), R4.1
GND: BOOT_BUTTON.1, BOOT_BUTTON.2, C1.2, C1_BAT.2, C1_BAT1.2, C1_BAT2.2, C2.2, C2_BAT.2, C3.-, C4_USB.2, C5.2, C5_USB.2, C6.2, C7.2, C8.2, C9.2, C10.2, C10_SUPERCAP.1, CHANGE_BUTTON.1, CHANGE_BUTTON.2, C_DELAY.2, D1.2 (GND), D3.1 (K), D6.1, D8.1, D9.1, D10.1, D11.1, D12.1, EPD_C1.1, EPD_C2.1, EPD_C5.1, EPD_C6.1, EPD_C7.1, EPD_C8.1, EPD_C9.1, EPD_C10.1, EPD_C11.1, EPD_C12.1, IC1.3 (GND), IC4.2 (VSS), J1.8, J1.17, J1.MP1, J1.MP2, J2.A1, J2.A12, J2.B1, J2.B12, J2.MP1, J2.MP2, J2.MP3, J2.MP4, J3.1, J4.G1 (GND_1), J4.G2 (GND_2), J4.G3 (GND_3), J4.G4 (GND_4), J4.P6 (VSS), MCP73831.2 (VSS), R1_PWRUSB.1, R2.1, R2-USB.2, R2-USB1.1, R2_BAT.1, R4.2, RESET_BUTTON.1, RESET_BUTTON.2, SENSOR2.1 (GND), SENSOR2.5 (SDO), SENSOR2.7 (GND), SJ1.1, TP4.TP, TP5.TP, U1.4 (GND), U1.9 (EXP), U2.1 (GND), U2.28 (GND), U2.29_1 (GND), U2.29_2 (GND), U2.29_3 (GND), U2.29_4 (GND), U2.29_5 (GND), U2.29_6 (GND), U2.29_7 (GND), U2.29_8 (GND), U2.29_9 (GND), U3.13 (GND), U4.1 (CTG), U4.4 (GND), U4.6 (QSTRT), U4.9 (EP)
GPIO8: R1.2, U2.10 (IO8)
I2C_PW: C1.1, C2.1, R1-PINH.2, R2-PINH.2, SENSOR2.6 (VDDIO), U2.17 (IO19)
INT_RTC: R1-PINH1.1, TP15.TP, U2.8 (IO0), U3.3 (SQW/!INT)
IO/BOOT: BOOT_BUTTON.3, BOOT_BUTTON.4, C6.1, R_BOOT.1, U2.15 (IO9)
IO/CHANGE: C10.1, CHANGE_BUTTON.3, CHANGE_BUTTON.4, R_CHANGE.1, U2.23 (IO15)
MISO: D12.2, J4.P7 (DAT0), R8.1, TP6.TP, U1.2 (DO(IO1)), U2.27 (IO2)
MOSI: D11.2, J1.14, J4.P3 (CMD), R7.1, TP7.TP, U1.5 (DI(IO0)), U2.7 (IO7)
unnamed: J2.A5, R2-USB1.2
unnamed: C1_BAT1.1, D2.1 (CATHODE), IC4.1 (VIN), IC4.3 (CE), Q1.2 (S)
unnamed: MCP73831.1 (STAT), R1_BAT.2
unnamed: CHG_LED.C, R1_BAT.1
unnamed: J2.B5, R2-USB.1
unnamed: MCP73831.5 (PROG), R2_BAT.2
unnamed: C4.1, D3.2 (A), D4.1 (K)
unnamed: EPD_C6.2, J1.18
unnamed: C_DELAY.1, IC1.5 (CT)
unnamed: EPD_C8.2, J1.20
unnamed: EPD_C7.2, J1.19
unnamed: EPD_C1.2, J1.4
unnamed: EPD_C10.2, J1.22
unnamed: EPD_C2.2, J1.5
unnamed: EPD_C12.2, J1.24
unnamed: SENSOR2.2 (CSB), SENSOR2.8 (VDD)
unnamed: D7.1 (CATHODE), R_CAPACITOR.1
PREVGH: D5.1 (K), EPD_C9.2, J1.21
PREVGL: D4.2 (A), EPD_C11.2, J1.23
RESE: J1.3, Q3.2 (S), R3.2
RESE': R2.2, R3.1, SJ1.2
RESET: C5.1, IC1.1 (VOUT), RESET_BUTTON.3, RESET_BUTTON.4, R_RESET.1, U2.3 (EN)
RTC_RST: U2.16 (IO18), U3.4 (!RST)
RX: TP2.TP, U2.24 (RXD0/GPIO17)
SCK: D10.2, J1.13, J4.P5 (CLK), R6.1, TP8.TP, U1.6 (CLK), U2.6 (IO6)
SCL: J3.4, R2-PINH.1, SENSOR2.4 (SCK), U2.20 (IO22), U3.16 (SCL), U4.7 (SCL)
SDA: J3.3, R1-PINH.1, SENSOR2.3 (SDI), U2.19 (IO21), U3.15 (SDA), U4.8 (SDA)
SRC: C4.2, D5.2 (A), L1.1, Q3.3 (D)
SS_SD: D8.2, J4.P2 (CD/DAT3), R10.1, U2.4 (IO4)
TX: TP1.TP, U2.25 (TXD0/GPIO16)
USB_D+: D1.1 (I/O1_1), U2.14 (IO13)
USB_D-: D1.3 (I/O2_1), U2.13 (IO12)
VBAT: C2_BAT.1, MCP73831.3 (VBAT), Q1.3 (D), TP3.TP, U4.2 (CELL), U4.3 (VDD)
VBUS: C1_BAT.1, C4_USB.1, C5_USB.1, CHG_LED.A, D1.5 (VBUS), D2.2 (ANODE), MCP73831.4 (VIN), PFMF.050.1.2, Q1.1 (G), R1_PWRUSB.2, TP14.TP
VRTC: C8.1, C10_SUPERCAP.2, R_CAPACITOR.2, U3.14 (VBAT)
VUSB: J2.A4, J2.A9, J2.B4, J2.B9, PFMF.050.1.1

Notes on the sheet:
SD Card
USB C connector & ESD protection
LDO Voltage Regulator
Li-Po Battery Charging Controller
ESP32 C6
E-Paper Drive Circuit
Display Type Selector
E-Paper Display Header
EPD Power
Environmental Sensor BME688
Voltage Supervisor + Reset & Boot / IO Button
Battery ChargeLevel
RTC Module DS3231SN
Test Pads
Qwiic / Stemma QT
SPI ESD Protection Lines
External NORFlash64MB
OpenBook Schematic
DMG2305UX-7
SD0805S020S1R0
68uH
BME688
Duminica Ana-Maria

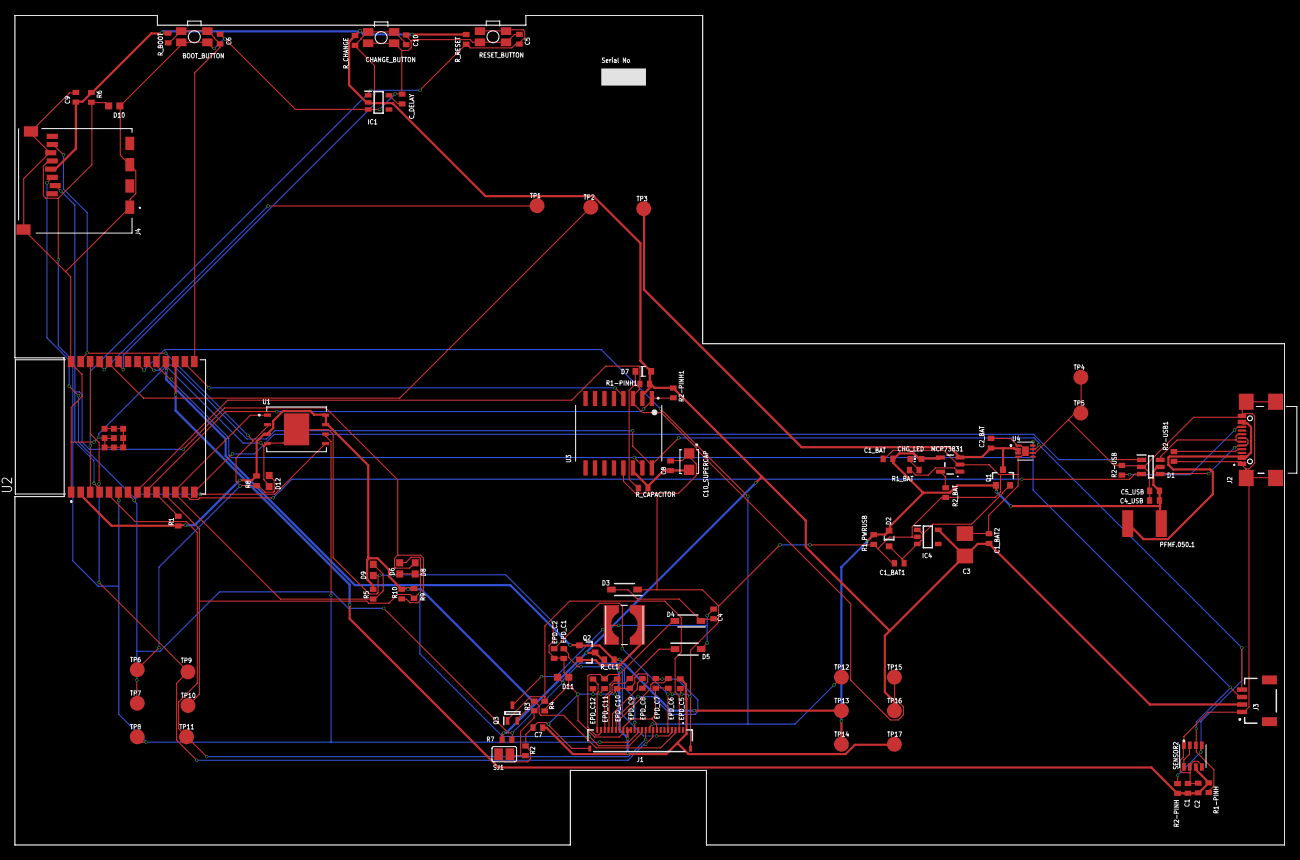
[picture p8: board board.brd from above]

Board: 2 copper layers, 170.2 x 111.2 mm, 103 parts (0 on the bottom side), 56 nets.

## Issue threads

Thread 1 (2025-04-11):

Net overlap: SCK, PREVGH, 3V3 si Pins overlap

alexiamihai, 2025-04-11:
Am observat cateva mesaje de warning ca "Net SCK overlaps pin" sau "Net 3V3 overlaps pin". Cel mai probabil, traseele trec prea aproape de un pad sau chiar il ating neintentionat. Ar fi bine sa verifici si sa refaci zonele respective ca sa nu existe scurtcircuite.

Exista o eroare de tip `"Pins overlap"`. Doua componente par sa fie prea apropiate sau chiar sa se suprapuna fizic. Poate o repozitionare usoara rezolva problema.

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

Closed 2025-04-11.

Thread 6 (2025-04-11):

Lipsa eticheta pe PCB

alexiamihai, 2025-04-11:
Lipsesc informatii minime despre proiect pe silkscreen, cum ar fi denumirea placii si serial no.

In rest, am observat ca cerintele au fost respectate:

Traseele de alimentare au grosimea potrivita, iar cele de semnal respecta latimea minima de 0.15mm – exact cum trebuie.
Nu am gasit unghiuri drepte in trasee – routing-ul e curat si conform cu cerintele.
Componentele sunt amplasate corect si complet, pe layer-ul TOP.
Layout-ul e bine echilibrat.
Am rulat DRC si nu aparr alte erori.

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

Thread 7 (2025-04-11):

Silkscreen

alexiamihai, 2025-04-11:
Silkscreen-ul ar mai avea nevoie de o verificare – in unele locuri apar si valori ale componentelor, nu doar denumiri. Ideal ar fi sa ramana doar referintele pentru claritate la asamblare.

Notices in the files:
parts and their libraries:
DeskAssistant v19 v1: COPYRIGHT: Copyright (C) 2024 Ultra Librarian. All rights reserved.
